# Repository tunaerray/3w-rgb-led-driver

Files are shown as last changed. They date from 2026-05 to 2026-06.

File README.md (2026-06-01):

# 3W RGB LED Driver

A custom-designed 3W RGB LED driver board with PWM dimming capability, developed for an Autonomous Underwater Vehicle (AUV).

## Overview

This board was designed to control the color output of a 3W RGB LED by adjusting each channel independently via PWM signals. The primary purpose is to support the AUV's image processing system by providing tunable, high-intensity underwater illumination.

## Features

- 3W RGB LED driving capability
- Independent PWM dimming for red, green, and blue channels
- Designed for underwater AUV integration
- Supports color-based object detection for computer vision tasks
- Tunable illumination for different underwater visibility conditions

## Use Case

Underwater visibility is limited, and colors can shift significantly with depth. By dynamically adjusting the RGB LED channels using PWM, the AUV's camera can capture more consistent color data.

This improves the reliability of image processing and object detection algorithms in underwater environments.

## Hardware

- **LED Type:** 3W RGB LED
- **Control Method:** Independent PWM dimming
- **Channels:** Red, green, and blue
- **Application:** Autonomous Underwater Vehicle lighting system
- **Purpose:** Image processing and object detection support

## Images

### PCB Front

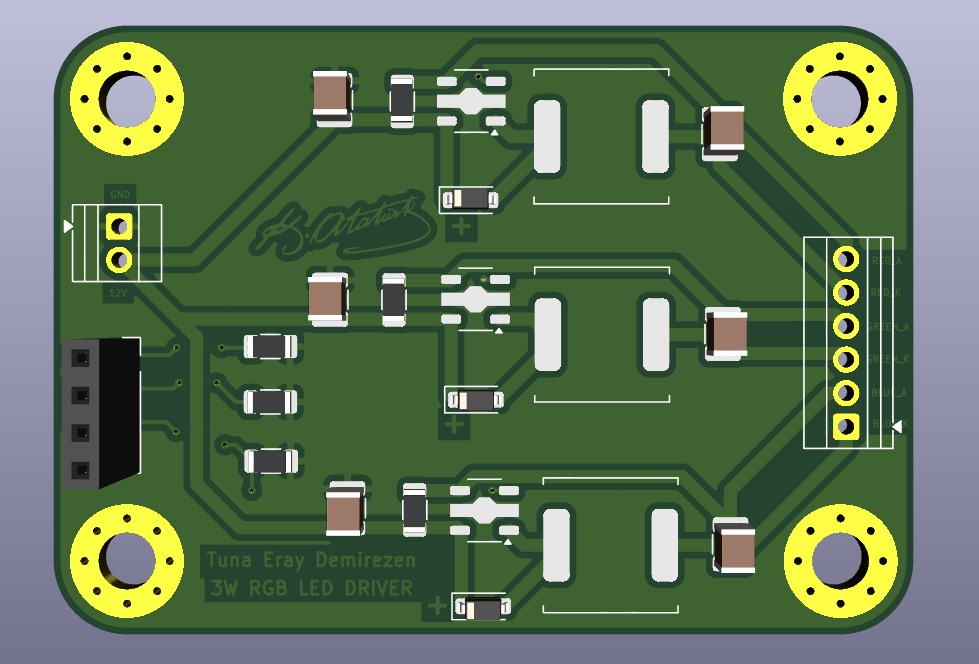
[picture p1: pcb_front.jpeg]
PCB Front


### PCB Back

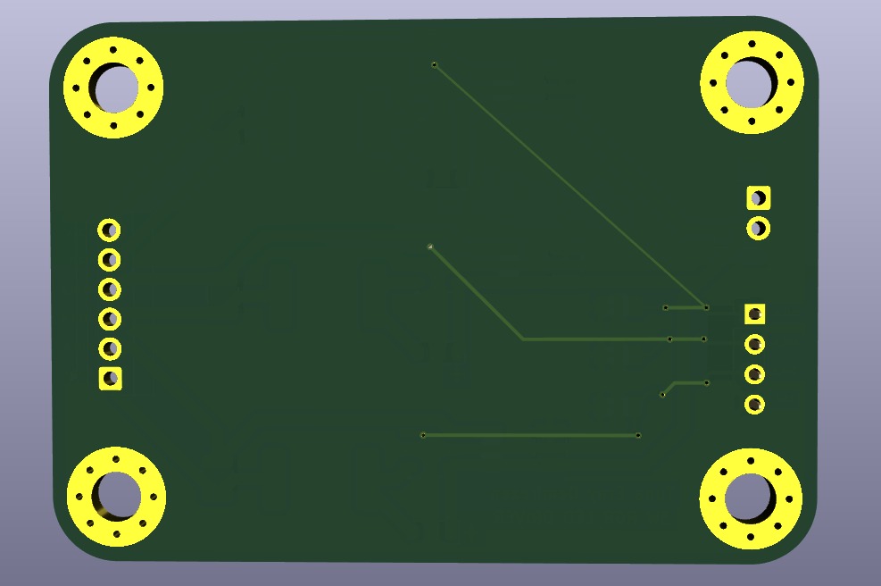
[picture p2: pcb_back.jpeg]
PCB Back


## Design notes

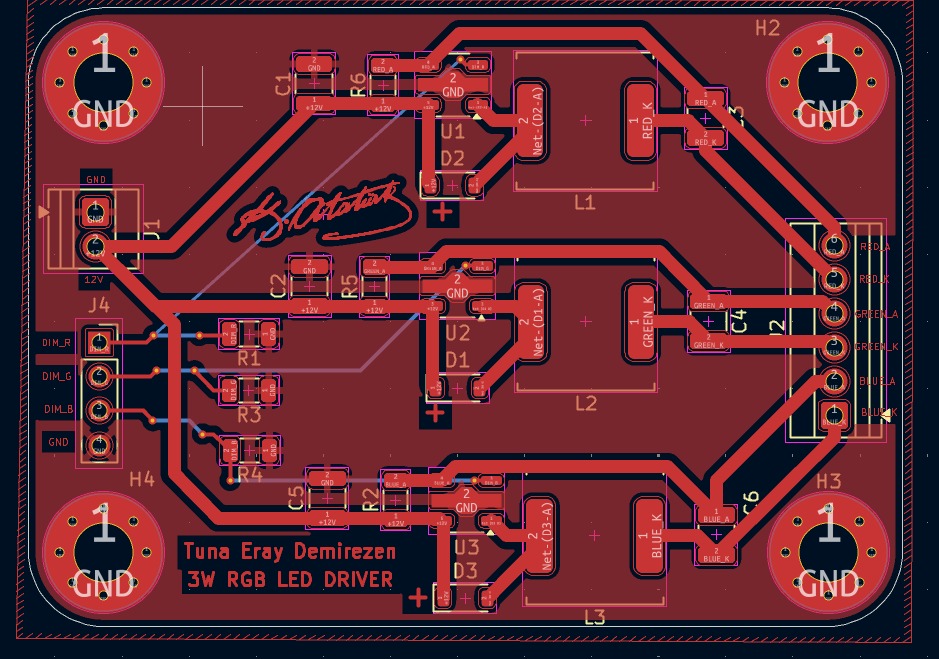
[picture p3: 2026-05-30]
pcb_layout.jpeg

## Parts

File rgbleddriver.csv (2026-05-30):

Reference | Qty | Value | DNP | Exclude from BOM | Exclude from Board | Footprint | Datasheet
C1,C2,C3,C4,C5,C6 | 6 | 10uF |  |  |  | Capacitor_SMD:C_1210_3225Metric | ~
D1,D2,D3 | 3 | D_Schottky |  |  |  | Diode_SMD:D_SOD-123 | ~
H1,H2,H3,H4 | 4 | MountingHole_Pad |  | Excluded from BOM |  | MountingHole:MountingHole_4.3mm_M4_Pad_Via | ~
J1 | 1 | Screw_Terminal_01x02 |  |  |  | TerminalBlock:TerminalBlock_Xinya_XY308-2.54-2P_1x02_P2.54mm_Horizontal | ~
J2 | 1 | Screw_Terminal_01x06 |  |  |  | TerminalBlock:TerminalBlock_Xinya_XY308-2.54-6P_1x06_P2.54mm_Horizontal | ~
J4 | 1 | Conn_01x04 |  |  |  | Connector_PinSocket_2.54mm:PinSocket_1x04_P2.54mm_Vertical | ~
L1,L2,L3 | 3 | 100uH |  |  |  | Inductor_SMD:L_SOREDE_SNR.1050_10x10x5mm | ~
R1,R3,R4 | 3 | 10k |  |  |  | Resistor_SMD:R_1206_3216Metric | ~
R2,R5,R6 | 3 | 0.3 |  |  |  | Resistor_SMD:R_1206_3216Metric | ~
U1,U2,U3 | 3 | PT4115 |  |  |  | Package_TO_SOT_SMD:SOT-89-5 | https://www.alldatasheet.com/datasheet-pdf/view/1141911/ETC2/PT4115.html

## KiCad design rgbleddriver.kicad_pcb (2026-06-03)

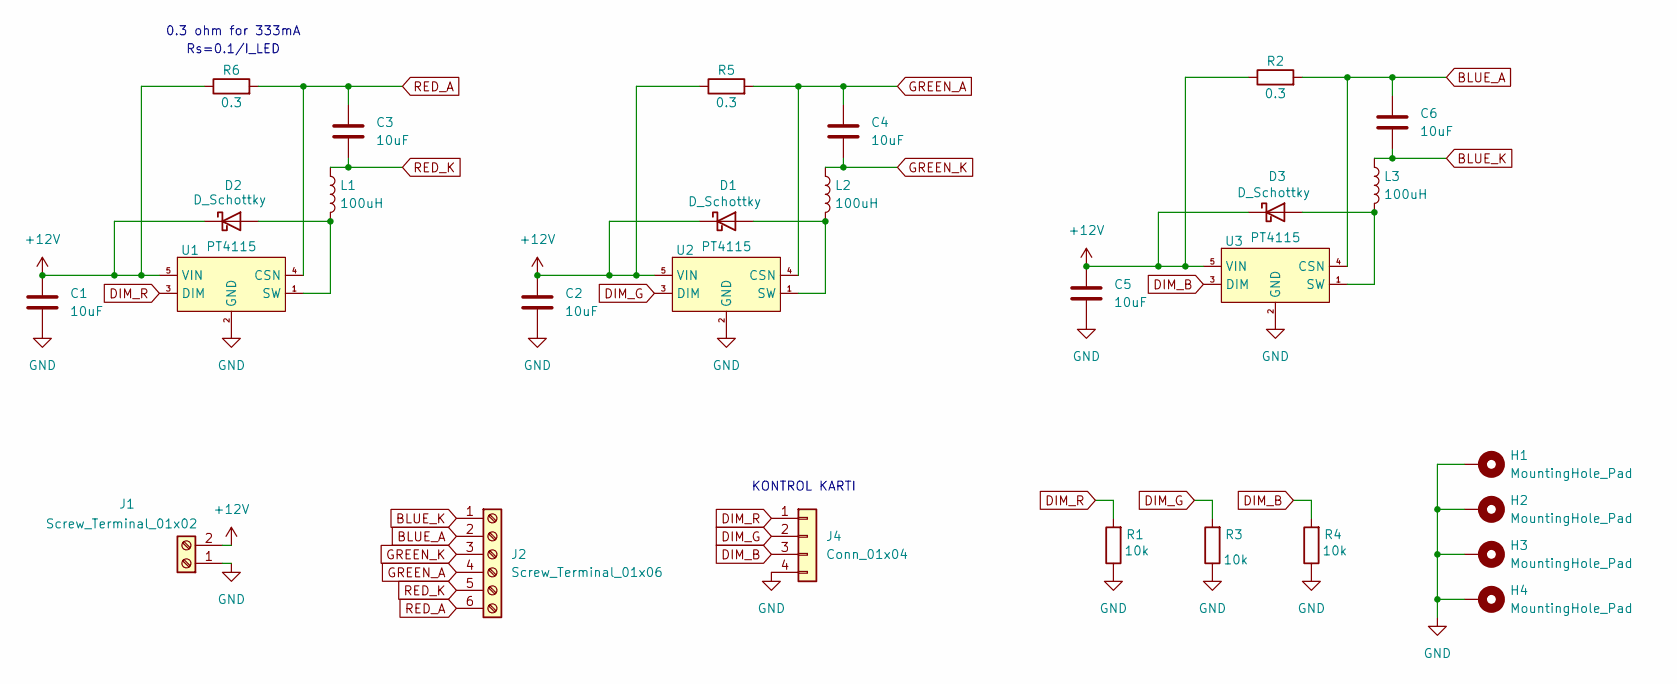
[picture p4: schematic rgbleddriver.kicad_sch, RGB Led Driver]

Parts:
C1, C2, C3, C4, C5, C6: 10uF; C_1210_3225Metric
D1, D2, D3: D_Schottky; D_SOD-123
H1, H2, H3, H4: MountingHole_Pad; MountingHole_4.3mm_M4_Pad_Via
J1: Screw_Terminal_01x02; TerminalBlock_Phoenix_PT-1,5-2-3.5-H_1x02_P3.50mm_Horizontal
J2: Screw_Terminal_01x06; TerminalBlock_Phoenix_PT-1,5-6-3.5-H_1x06_P3.50mm_Horizontal
J4: Conn_01x04; PinSocket_1x04_P2.54mm_Vertical
L1, L2, L3: 100uH; L_SOREDE_SNR.1050_10x10x5mm
R1, R3, R4: 10k; R_1206_3216Metric
R2, R5, R6: 0.3; R_1206_3216Metric
U1, U2, U3: PT4115; SOT-89-5

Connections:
+12V: C1.1, C2.1, C5.1, D1.1 (K), D2.1 (K), D3.1 (K), J1.2, R2.1, R5.1, R6.1, U1.5 (VIN), U2.5 (VIN), U3.5 (VIN)
BLUE_A: C6.1, J2.2, R2.2, U3.4 (CSN)
BLUE_K: C6.2, J2.1, L3.1
DIM_B: J4.3, R4.2, U3.3 (DIM)
DIM_G: J4.2, R3.2, U2.3 (DIM)
DIM_R: J4.1, R1.2, U1.3 (DIM)
GND: C1.2, C2.2, C5.2, H1.1, H2.1, H3.1, H4.1, J1.1, J4.4, R1.1, R3.1, R4.1, U1.2 (GND), U2.2 (GND), U3.2 (GND)
GREEN_A: C4.1, J2.4, R5.2, U2.4 (CSN)
GREEN_K: C4.2, J2.3, L2.1
unnamed: D1.2 (A), L2.2, U2.1 (SW)
unnamed: D2.2 (A), L1.2, U1.1 (SW)
unnamed: D3.2 (A), L3.2, U3.1 (SW)
RED_A: C3.1, J2.6, R6.2, U1.4 (CSN)
RED_K: C3.2, J2.5, L1.1

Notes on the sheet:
0.3 ohm for 333mA
KONTROL KARTI
Rs=0.1/I_LED

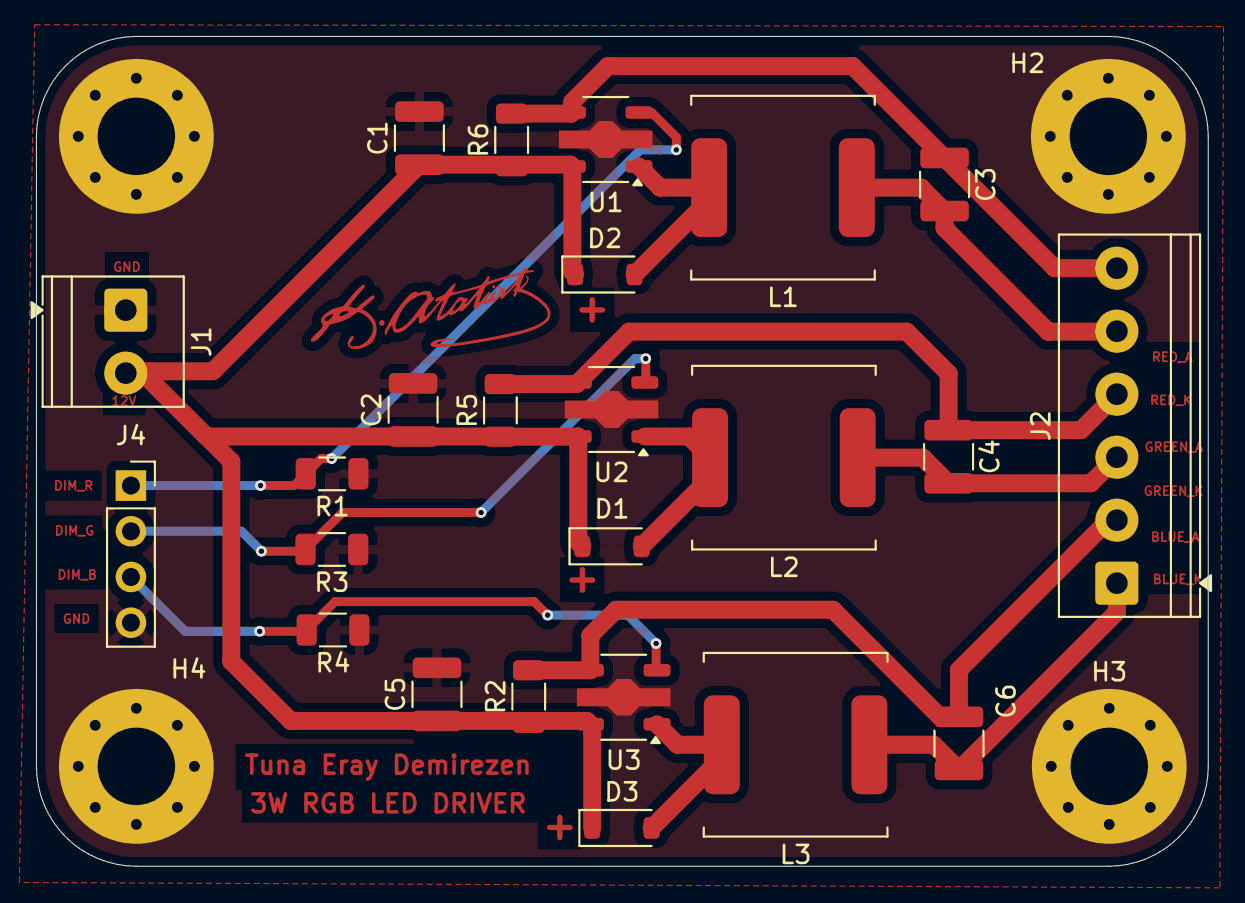
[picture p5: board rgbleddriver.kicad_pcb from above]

Board: 2 copper layers, 65.1 x 46.1 mm, 28 parts (0 on the bottom side), 14 nets.

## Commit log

2026-05-30 Add KiCad PCB project files and BOM
    [rgbleddriver.csv, rgbleddriver.kicad_pcb, rgbleddriver.kicad_sch]
2026-05-30 Add PCB images (front, back, layout)
2026-05-30 Add PCB images to README
2026-05-30 Add Gerber files for PCB manufacturing
2026-06-01 Revise README for improved clarity and detail
    Updated the README to enhance clarity and detail regarding the RGB LED driver board's features, use case, and hardware specifications.
2026-06-03 Update revised RGB LED driver PCB files
    [rgbleddriver.kicad_pcb]
2026-06-03 Move images and gerber zip to repo root, remove subfolders
